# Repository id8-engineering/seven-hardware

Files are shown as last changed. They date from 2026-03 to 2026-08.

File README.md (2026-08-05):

# Seven Hardware

Seven is a rapid‑prototyping platform for low‑cost, low‑power connected
IoT devices with integrated LTE cellular connectivity.

Designed for teams moving from concept to deployment, Seven bridges the gap
between traditional development boards and finalized products—making it ideal
for pilot projects, field trials, and early production runs.

Specification:

* Nordic Semiconductor nRF9151 SiP with integrated LTE-M/NB-IoT modem and GPS
  * 64 MHz Arm Cortex-M33
  * 256 KiB RAM
  * 1 MiB flash
* 6-36 V input voltage
* 2 x mikroBUS™ sockets for easy expansion with Click Boards
* RGB LED
* Passive buzzer
* Programming interface (SWD) via Raspberry Pi Debug Probe
* Debug interface (UART) via Raspberry Pi Debug Probe
* Industrial temperature range (-40 to 85 Celsius)

The software stack is built on the Zephyr Project, providing a robust, secure,
and scalable RTOS foundation. It includes ready‑to‑use modules for over‑the‑air
(OTA) updates and cloud connectivity, with primary support for AWS IoT.

By adopting the widely used mikroBUS™ add‑on standard, Seven offers access to
thousands of off‑the‑shelf Click Boards. This makes it easy to extend the
platform with sensors (motion, proximity, temperature, etc.) or interfaces such
as RS‑232, RS‑485, CAN, and more—without custom hardware design.

Seven is open source and open hardware, giving developers complete transparency
and control to customize, manufacture, and evolve their products without vendor
lock‑in.

---

This repository contains the KiCad project, documentation, and manufacturing
files required to build the Seven hardware board.

<p align="center">
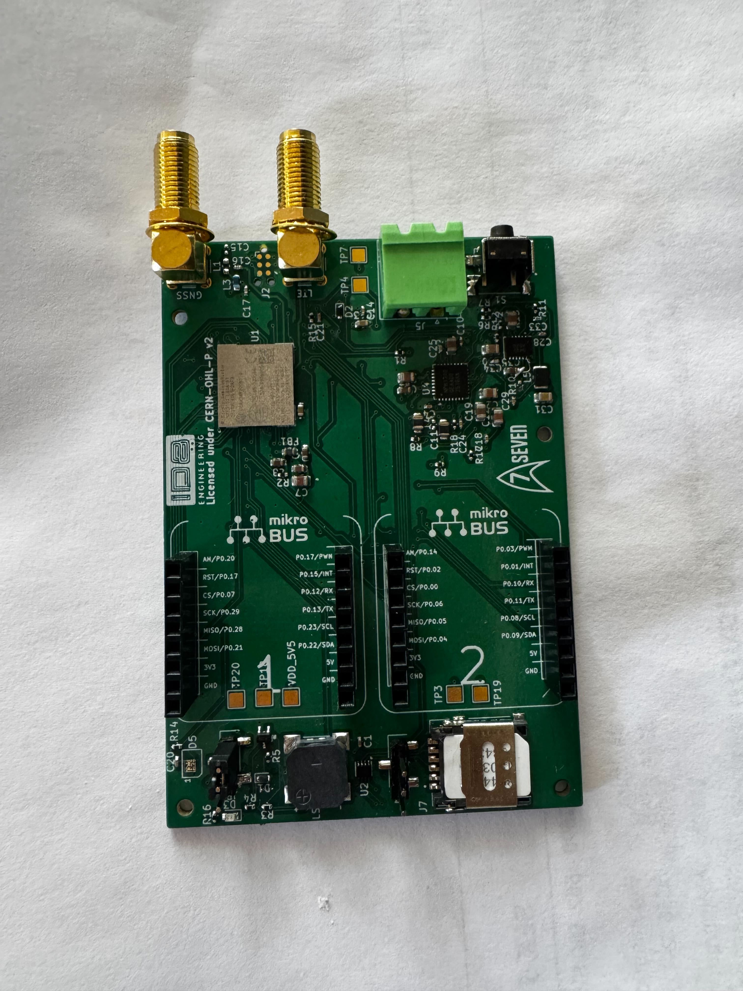
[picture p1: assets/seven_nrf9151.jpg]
Seven nRF9151
  
</p>

## License

Copyright 2026 ID8 Engineering AB

This source describes Open Hardware and is licensed under the CERN-OHL-P v2.

You may redistribute and modify this source and make products using it
under the terms of the CERN-OHL-P v2 (https://cern.ch/cern-ohl).

This source is distributed WITHOUT ANY EXPRESS OR IMPLIED
WARRANTY, INCLUDING OF MERCHANTABILITY, SATISFACTORY QUALITY
AND FITNESS FOR A PARTICULAR PURPOSE. Please see the CERN-OHL-P v2
for applicable conditions.

This source distribution includes the companion documents required by
the CERN-OHL-P v2 guide:

- [LICENSE](LICENSE)
- [CERN-OHL-P-v2-user-guide.md](CERN-OHL-P-v2-user-guide.md)
- [CHANGES.txt](CHANGES.txt)

---

## Report issues

If you run into problems, you can ask for help in our
[issue tracker](https://github.com/id8-engineering/seven-hardware/issues) on
GitHub.

## Maintainers

Maintained by [ID8 Engineering AB](https://github.com/id8-engineering/).

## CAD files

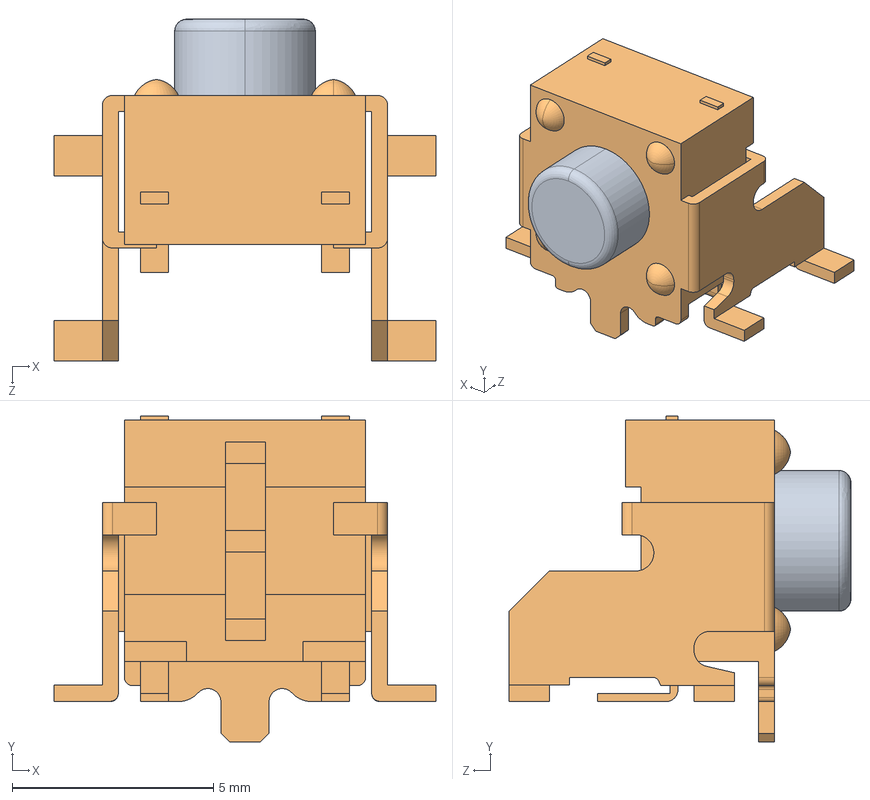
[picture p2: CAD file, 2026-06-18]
kicad/3dmodels/TL3336AF160Q--3DModel-STEP-510211.STEP
9.50 x 8.10 x 8.50 mm

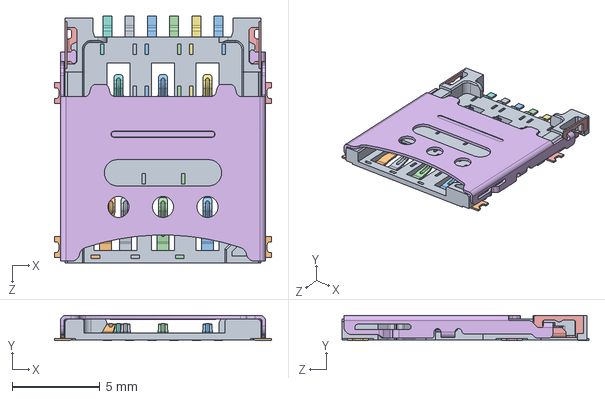
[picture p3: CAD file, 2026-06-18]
kicad/3dmodels/NSIM-2-C--3DModel-STEP-1.STEP
12.4 x 1.43 x 14.1 mm

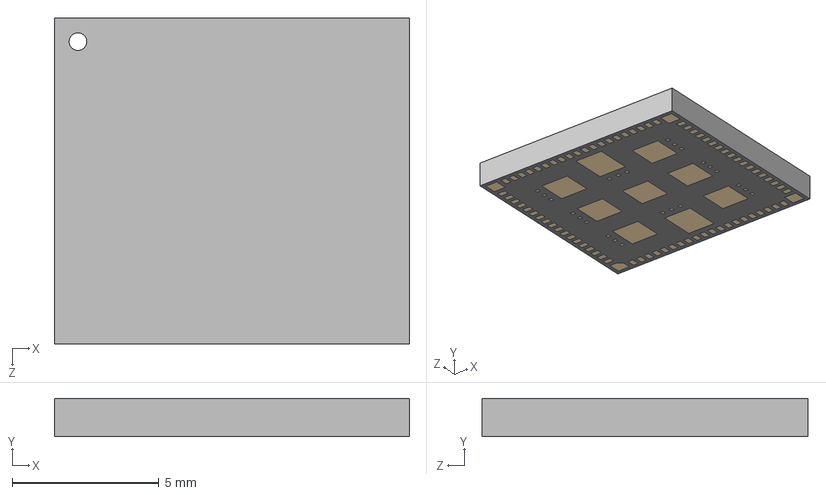
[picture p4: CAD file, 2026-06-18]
kicad/3dmodels/NRF9151-LACA-R--3DModel-STEP-510211.STEP
12.1 x 1.30 x 11.1 mm

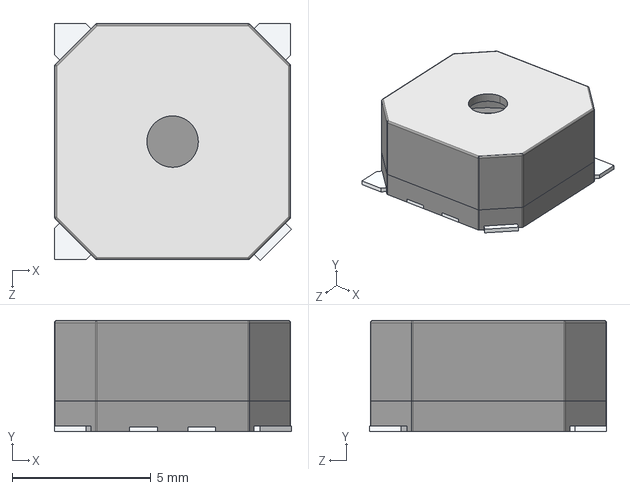
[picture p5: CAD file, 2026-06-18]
kicad/3dmodels/CMT-8504-100-SMT-TR--3DModel-STEP-1.STEP
8.53 x 4.00 x 8.53 mm

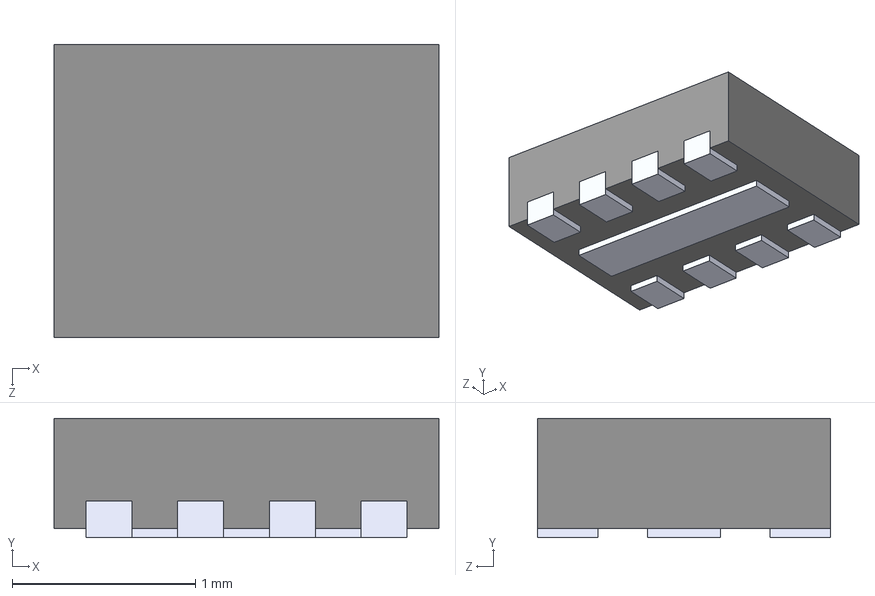
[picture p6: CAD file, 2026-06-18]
kicad/3dmodels/TPD3F303DPVR--3DModel-STEP-56544.STEP
2.10 x 0.65 x 1.60 mm

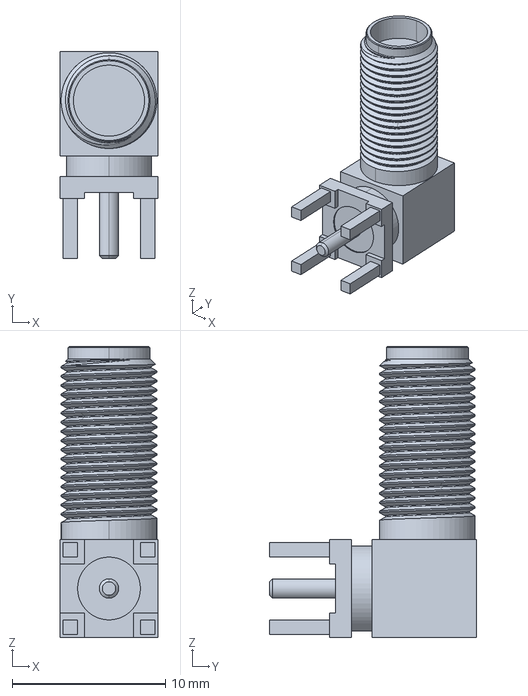
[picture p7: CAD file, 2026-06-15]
kicad/3dmodels/c-2081679-1-1-3d.igs
6.40 x 13.5 x 19.0 mm

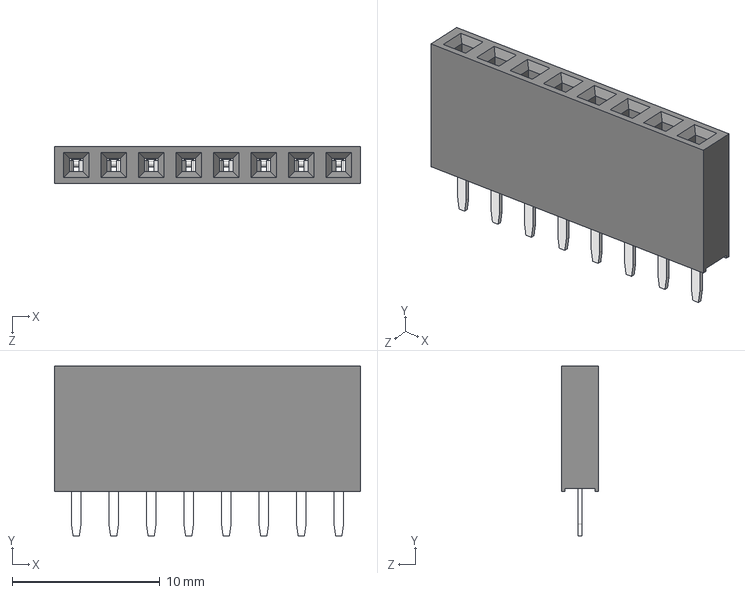
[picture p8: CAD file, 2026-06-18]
kicad/3dmodels/M20-7820842--3DModel-STEP-56544.STEP
20.7 x 11.5 x 2.50 mm

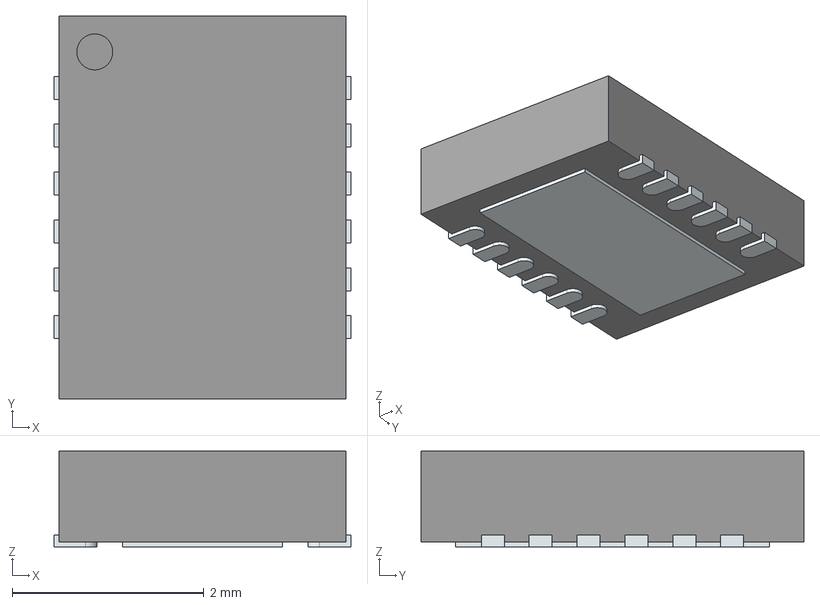
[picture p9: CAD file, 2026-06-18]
kicad/3dmodels/ISL85410FRZ-T7A.stp
3.10 x 4.00 x 1.00 mm
ThermalPin
PinsArrayLR

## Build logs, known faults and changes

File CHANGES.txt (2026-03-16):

2026-03-16
Released sources under CERN-OHL-P v2 license

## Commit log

2026-02-04 init: kicad project
    [seven.kicad_pcb, seven.kicad_sch]
2026-02-05 fix: structure project with examples for early testing
    [seven.kicad_pcb, seven.kicad_sch]
2026-02-05 feat: add nrf9151 with LED
    [seven.kicad_pcb, seven.kicad_sch]
2026-03-02 feat(): add nrf9151 symbol
    [seven.kicad_pcb, seven.kicad_sch]
2026-03-02 symbol: add mikroBUS fp and sym
    [seven.kicad_pcb, seven.kicad_sch]
2026-03-03 fix: fix erc errors to be able to merge drc&erc workflow
    [seven.kicad_sch]
2026-03-04 feat: add mikrobussocket connections feat: add powersupply MSTB connector and buck converter circuit (3-36V) -> 5V feat: add buck converter circuit 5V -> 3V3
    [seven.kicad_pcb, seven.kicad_sch]
2026-03-04 fix: change symbol u3 to seven-lib it was imported from wrong lib
    [seven.kicad_sch]
2026-03-04 fix(schematic): change all power symbols to local project sym-lib
2026-03-04 fix(): change all symbols to contain default fp from project fp lib
    [seven.kicad_pcb, seven.kicad_sch]
2026-03-05 fix: symbols had not been fixed for some reason
    [seven.kicad_sch]
2026-03-05 chore(CI): add kicad action
2026-03-05 feat: add power LED
    [seven.kicad_sch]
2026-03-05 fix: dont share spi and i2c data lines
    [seven.kicad_sch]
2026-03-05 feat: add system controlled RGB LED sk6805-EC15
    [seven.kicad_sch]
2026-03-06 fix: restruct schematics to hierarchical sheet
    [mcu.kicad_sch, mikroBUS.kicad_sch, power_LED.kicad_sch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]
2026-03-06 fix: split mikroBUS socket sheets in to 2
    [mikroBUS_1.kicad_sch, mikroBUS_2.kicad_sch, seven.kicad_sch]
2026-03-06 feat: add JTAG SWD interface TC2030 Tag Connect
    To program SEVEN we will use the JTAG standard SWD with the Tag Connect called TC2030
    [JTAG.kicad_sch, mcu.kicad_sch, seven.kicad_sch]
2026-03-06 feat: add UART debugger headers
    [mcu.kicad_sch, seven.kicad_sch, uart_debugger.kicad_sch]
2026-03-06 feat: add reset button
    [reset_button.kicad_sch, seven.kicad_sch]
2026-03-09 feat: add buzzer
    [buzzer.kicad_sch, mcu.kicad_sch, reset_button.kicad_sch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]
2026-03-09 feat: add sim card holder
    [SIM_card.kicad_sch, mcu.kicad_sch, seven.kicad_sch]
2026-03-09 fix: set directions on the hierarchical labels
    [JTAG.kicad_sch, SIM_card.kicad_sch, mcu.kicad_sch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]
2026-03-09 fix: fix UART crossed rx and tx
    [seven.kicad_sch]
2026-03-09 feat: add decoupling capacitors and ferrite bead for nRF9151 VDD, VDD_GPIO, and DEC0
    [mcu.kicad_sch]
2026-03-10 feat: add placeholderr circuits for GNSS and LTE antennas
    [antenna_GNSS.kicad_sch, antenna_LTE.kicad_sch, mcu.kicad_sch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]
2026-03-10 feat: change SIM card 69304302061 to NSIM-2-C
    [SIM_card.kicad_sch]
2026-03-10 feat: update GNSS circuit
    [antenna_GNSS.kicad_sch, antenna_LTE.kicad_sch]
2026-03-10 fix: change GNSS circuit to follow nRF9151DK SMA connectors
    [antenna_GNSS.kicad_sch, seven.kicad_sch]
2026-03-10 docs: update component description for TPS62162DSG
    [power_supply.kicad_sch, seven.kicad_sch]
2026-03-10 feat: replace placeholder buzzer circuit with final circuit
    [SIM_card.kicad_sch, buzzer.kicad_sch]
2026-03-11 feat: remake power management and use the same as the reference DK
    [JTAG.kicad_sch, PMIC.kicad_sch, SIM_card.kicad_sch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]
2026-03-12 feat: swap reset button to TL3336AF160Q
    [reset_button.kicad_sch]
2026-03-12 feat: update mikroBUS footprint to standard recommendation
2026-03-12 docs: update documentation to be more accurate
    [JTAG.kicad_sch, PMIC.kicad_sch, SIM_card.kicad_sch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]
2026-03-13 feat: add jumper to VDD_GPIO to expose either 1V8 or 3V3
    [mcu.kicad_sch, uart_debugger.kicad_sch]
2026-03-16 fix: change C fp to smaller one.
    [PMIC.kicad_sch, SIM_card.kicad_sch, antenna_GNSS.kicad_sch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]
2026-03-16 fix: change R fp to a smaller one
    [PMIC.kicad_sch, antenna_GNSS.kicad_sch, buzzer.kicad_sch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]
2026-03-18 fix: changes made according to review meeting
    [JTAG.kicad_sch, PMIC.kicad_sch, antenna_GNSS.kicad_sch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]
2026-03-18 fix: satisfy warnings in pcb
    [PMIC.kicad_sch, buzzer.kicad_sch]
2026-03-24 feat(PCB): set component-placement example on PCB
    This pr will fail due to DRC, skip this and lets have a conversation
    about the placement only
    [JTAG.kicad_sch, PMIC.kicad_sch, SIM_card.kicad_sch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]
2026-03-27 fix: remove vias from pads
    [seven.kicad_pcb]
2026-04-22 fix: fix issues from seven prototype 1
    see https://github.com/id8-engineering/seven-bringup/issues/22
    [PMIC.kicad_sch, buzzer.kicad_sch, mcu.kicad_sch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]
2026-04-22 feat: move TC2030
    [mcu.kicad_sch, power_supply.kicad_sch, seven.kicad_pcb]
2026-04-23 fix: swap silkscreen for mikrobus numbers
    [seven.kicad_pcb]
2026-04-24 feat: flip mikrobus connections
    [mcu.kicad_sch, mikroBUS_1.kicad_sch, mikroBUS_2.kicad_sch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]
2026-04-29 feat: change TPD3F303DPVR footprint and symbol
    [SIM_card.kicad_sch, seven.kicad_pcb]
2026-04-29 feat: remove UART header debugger, use RTT console for debugging
    [mcu.kicad_sch, seven.kicad_pcb, seven.kicad_sch]
2026-04-30 feat: change SIM_1V8 to be a output from MCU and own its own power rail
    [SIM_card.kicad_sch, mcu.kicad_sch, seven.kicad_pcb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]
2026-05-11 feat: add UART pin header back again
    [mcu.kicad_sch, seven.kicad_pcb, seven.kicad_sch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]
2026-05-28 fix: fix switch footprint
    [antenna.kicad_sch, seven.kicad_pcb, system_LED.kicad_sch]
2026-06-15 feat: add sma connectors as 3d models
    [c-2081679-1-1-3d.igs, seven.kicad_pcb]
2026-06-17 fix: change PWN1 to PWM1 wrong spelling, no route change needed
    [mcu.kicad_sch, seven.kicad_pcb, seven.kicad_sch]
2026-06-17 feat: add the rest of 3d models to support full rendered 3D PCB
    [CMT-8504-100-SMT-TR--3DModel-STEP-1.STEP, ISL85410FRZ-T7A.stp, M20-7820842--3DModel-STEP-56544.STEP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]
2026-07-23 fix: update seven logo silkscreen
    [seven.kicad_pcb]
2026-08-03 feat: Update for 0.3.0 release
    Add power rail controlled by PMIC load switch.
    Change location for testpads to be cleaner
    remove TC2030 and add JST connector for RPI debug probe
    remove VDD_GPIO jumper
    fix silkscreen
    [JST-SH.kicad_sch, PMIC.kicad_sch, antenna_GNSS.kicad_sch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]
2026-08-05 docs(README): update README with new supported debug probe (Raspberry Pi Debug probe)
2026-08-06 fix: morePCB requested we change slot lenght of button mounting hole to 2,4 mm
    [seven.kicad_pcb]
2026-09-07 fix: swap swclk and swdio for jst-sh contact
    [JST-SH.kicad_sch, seven.kicad_pcb]
2026-11-04 chore(buzzer): replace obsolete transistor with the higher power mosfet BSS214NW
2026-11-09 fix(Q1): use symbol and footprint from seven lib
2026-11-09 fix(Q1): add pull down resistor R9
